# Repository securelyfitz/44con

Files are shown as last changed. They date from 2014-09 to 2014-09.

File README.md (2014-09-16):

44CON 2014 Badge
================

Based on the Dangerous Prototypes Bus Pirate V3c

Summary of changes:
-------------------
- changed PCB outline in dp_pcb.lbr
- added 44CON text in 44context.lbr
- added 1.8v LDO for using cpld without FTDI
- added LEDs and resistors on JP2 spare pins
- added 5x7mm Oscillator on pin 28
- added solder jumper near vtarget jumper

PCB Files
---------
* .sch and .brd: eagle schematic and board files 
* .lbr: eagle libraries for board outline and text items 
* .G* and .TXT: gerber files for fabricating board

CPLD Files
----------
* conled.v defines led flashing logic
* conled.v defines I/O pin assignments
* conled.jed xilinx bitstream file
* default.svf and default.xsvf bistream in generic format

Build options:
-------------
1. Generic USB Blaster for JTAG OCD, programming, and testing
1. Bare minimum CPLD build for flashing lights
1. Bare minimum CPLD build for cheap glitching

USB Blaster Build:
-----------------
see details on dangerous prototypes website:
http://dangerousprototypes.com/docs/Bus_Blaster_v3_design_overview

Flashy Light Build:
------------------

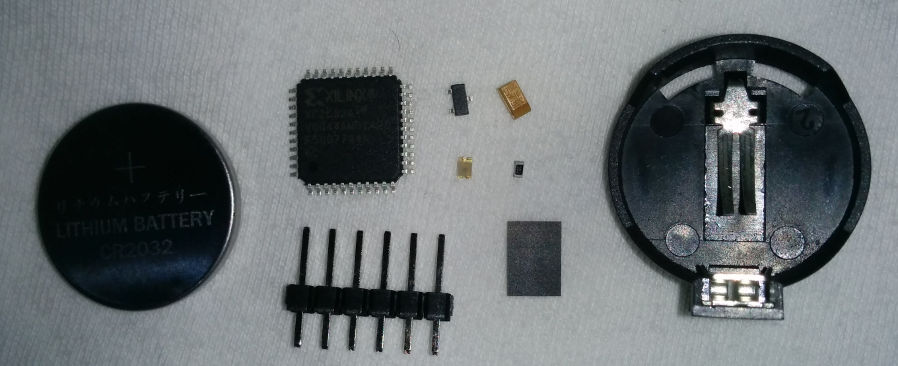
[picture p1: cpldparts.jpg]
cpld components


parts:
------
* CR2032 battery
* xilinx xc2c32a CPLD
* lm3480 1.8v regulator (note pinout!!!)
* 3.3nF tantalum capacitor
* 0805 LED x5
* 0603 50 ohm resistor
* .1" header for programming
* 5x7mm 50mhz (ish) oscillator
* CR2032 holder

building:
--------
1. solder battery holder onto the back of the board between jp2 3.3v pin and a JTAG GND pin
1. solder over the solder jumper in the upper right corner of the board
1. solder lm3480 just below and in between the FTDI and CPLD chips
  * if you have an AP7313 the pinout is different, rotate it clockwise 120 degrees and solder it
1. solder the tantalum capacitor on C2 with + towards the top of the PCB
1. put the CR2032 in and test that you have 3ish  volts on the 3.3v pins and 1.8 volts on the right lead of the regulator
1. remove the CR2032
1. solder the oscillator in the bottom right. Pin1 is in the far bottom right
1. solder the CPLD in place. Pin1 goes up
1. solder the resistors in place between the 2014 on the bottom. Resistors go on the upper pads
1. solder the LEDs below the resistors. + is to the left, - to the right
1. put the CR2032 back in and test for output from pin 3 of the oscillator (top left) with a multemeter to make sure it's not 0v
1. using a jtag programmer - Xilinx cable, Bus blaster, or a bus pirate in SVF mode - configure your CPLD and watch lights flash!

troubleshooting:
---------------
* if you can't recognize/configure the CPLD or lights are very dim, it could be a power issue. double check the 1.8v regulator and that the capacior is in the right direction.
* if the LEDs go on but don't flash, check your oscillator

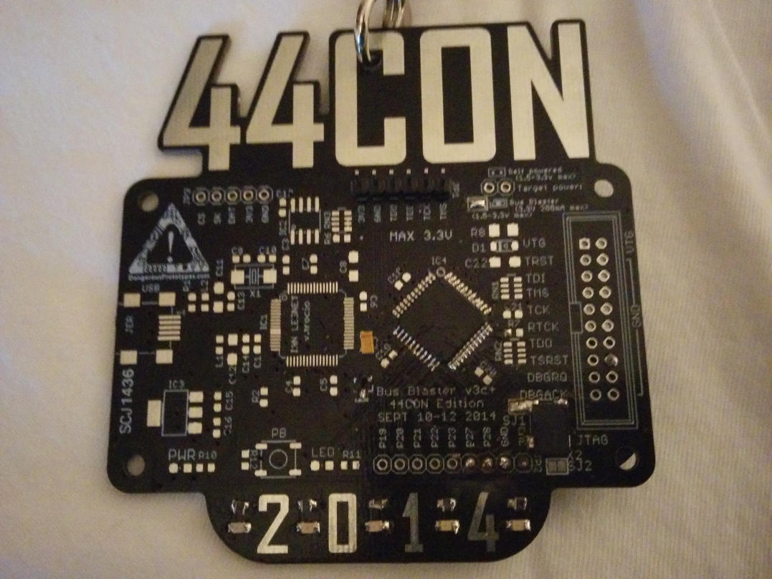
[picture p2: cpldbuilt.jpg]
cpld built


Glitching build:
----------------
same as flashy light build, though LEDS are optional. WIP to use it for glitching arduinos and/or XBOX360s

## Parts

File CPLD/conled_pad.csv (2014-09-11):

Release 8.1i - Fit P.20131013
Copyright(c) 1995-2003 Xilinx Inc. All rights reserved
9-10-2014 5:23PM
NOTE: This file is designed to be imported into a spreadsheet program
such as Microsoft Excel for viewing | printing and sorting. The comma ' | '
character is used as the data field separator.
This file is also designed to support parsing.
Input file: conled.ngd
output file: conled_pad.csv
Part type: xc2c32a
Speed grade: -6
Package: vq44
Pinout by Pin Number:
----- | ----- | ----- | ----- | ----- | ----- | ----- | ----- | ----- | -----
Pin Number | Signal Name | Pin Usage | Pin Name | Direction | IO Standard | IO Bank Number | {blank} | Slew Rate | Termination | {blank} | Voltage | Constraint
P1 | KPR |  | I/O/GCK2 |  |  | 1
P2 | KPR |  | I/O |  |  | 1
P3 | KPR |  | I/O |  |  | 1
P4 | GND |  | GND
P5 | KPR |  | I/O |  |  | 1
P6 | KPR |  | I/O |  |  | 1
P7 |  | VCCIO-UNUSED | VCCIO |  |  | 1
P8 | KPR |  | I/O |  |  | 1
P9 | TDI |  | TDI
P10 | TMS |  | TMS
P11 | TCK |  | TCK
P12 | KPR |  | I/O |  |  | 1
P13 | KPR |  | I/O |  |  | 1
P14 | KPR |  | I/O |  |  | 1
P15 |  | VCC | VCC
P16 | KPR |  | I/O |  |  | 1
P17 | GND |  | GND
P18 | KPR |  | I |  |  | 2
P19 | led0 | O | I/O | OUTPUT | LVCMOS18 | 2 |  | FAST
P20 | led1 | O | I/O | OUTPUT | LVCMOS18 | 2 |  | FAST
P21 | led2 | O | I/O | OUTPUT | LVCMOS18 | 2 |  | FAST
P22 | led3 | O | I/O | OUTPUT | LVCMOS18 | 2 |  | FAST
P23 | led4 | O | I/O | OUTPUT | LVCMOS18 | 2 |  | FAST
P24 | TDO |  | TDO
P25 | GND |  | GND
P26 |  | VCCIO-1.8 | VCCIO |  |  | 2
P27 | led5 | O | I/O | OUTPUT | LVCMOS18 | 2 |  | FAST
P28 | KPR |  | I/O |  |  | 2
P29 | KPR |  | I/O |  |  | 2
P30 | KPR |  | I/O/GSR |  |  | 2
P31 | KPR |  | I/O/GTS2 |  |  | 2
P32 | KPR |  | I/O/GTS3 |  |  | 2
P33 | KPR |  | I/O/GTS0 |  |  | 2
P34 | KPR |  | I/O/GTS1 |  |  | 2
P35 |  | VCCAUX | VAUX
P36 | KPR |  | I/O |  |  | 2
P37 | KPR |  | I/O |  |  | 2
P38 | KPR |  | I/O |  |  | 2
P39 | KPR |  | I/O |  |  | 1
P40 | KPR |  | I/O |  |  | 1
P41 | KPR |  | I/O |  |  | 1
P42 | KPR |  | I/O |  |  | 1
P43 | KPR |  | I/O/GCK0 |  |  | 1
P44 | KPR |  | I/O/GCK1 |  |  | 1
To preserve the pinout above for future design iterations in
Project Navigator simply execute the (Lock Pins) process
located under the (Implement Design) process in a toolbox named
(Optional Implementation Tools) or invoke PIN2UCF from the
command line. The location constraints will be written into your
specified UCF file

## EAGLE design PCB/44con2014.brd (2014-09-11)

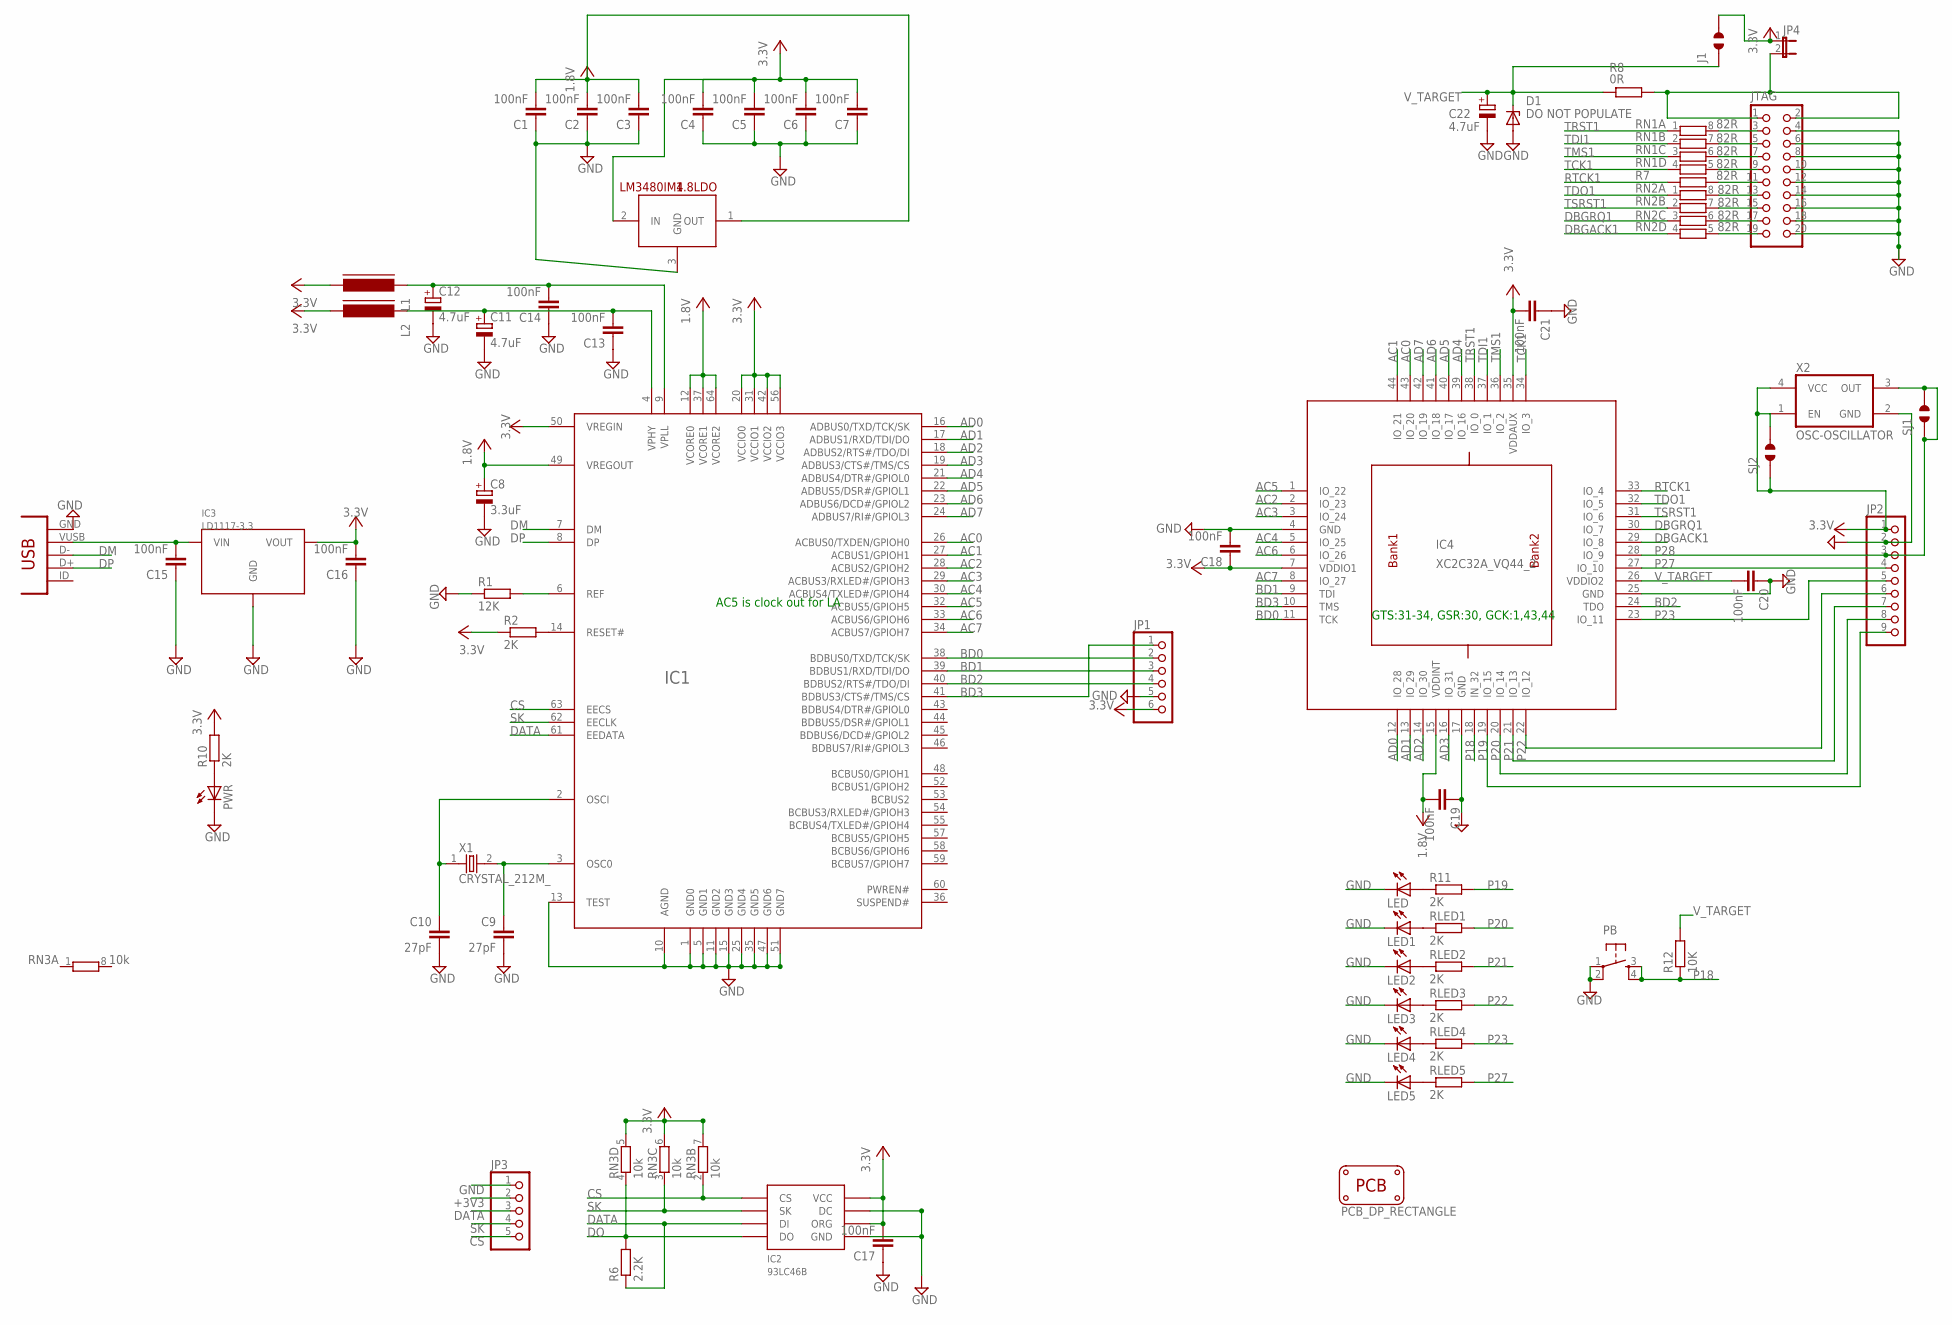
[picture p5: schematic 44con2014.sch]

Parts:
1.8LDO: LM3480IM4; SOT23-3
C1, C2, C3, C4, C5, C6, C7, C13, C14, C15, C16, C17, C18, C19, C20, C21: 100nF; C603
C8: 3.3uF; SMC_A
C9, C10: 27pF; C603
C11, C12, C22: 4.7uF; SMC_A
D1: DO NOT POPULATE; SOD-123
IC1: FT2232H; LQFP64
IC2: 93LC46B; SOIC8
IC3: LD1117-3.3; SOT223
IC4: XC2C32A_VQ44_2; VQ44
J1: JUMPER_SOLDER_1X2
JP1: PINHD-1X6; 1X06
JP2: PINHD-1X9; 1X09
JP3: PINHD-1X5; 1X05
JP4: JP1EJP; 1X02
JTAG: CON_HEADER_2X10-SHROUDED; PINSHRD_PTH_2X10
L1, L2: FERRITE_BEAD603; FB603
LED, LED1, LED2, LED3, LED4, LED5: LED805; LED-805
PB: SW-SMD-SMALL; TACT_SWITCH_SMALL
PCB3: PCB_DP_RECTANGLE; 44CON2014
PWR: LEDCHIPLED_0805; CHIPLED_0805
R1: 12K; R603
R2, R10, R11: 2K; R603
R6: 2.2K; R603
R7: 82R; R603
R8: 0R; R1206
R12: 10K; R603
RLED1, RLED2, RLED3, RLED4, RLED5: 2K; R603
RN1, RN2: 82R; RN8P-4R-CRA06S
RN3: 10k; RN8P-4R-CRA06S
SJ1, SJ2: JUMPER_SOLDER_1X2
USB: CON-USB-MINI-BUSB1; CONN_USB_MINI-B
X1: CRYSTAL_212M_; XTAL_4X6
X2: OSC-OSCILLATOR; OSCILLATOR_7X5_SMD

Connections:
1.8V: 1.8LDO.1 (OUT), C1.2, C2.2, C3.2, C8.+, C19.2, IC1.12 (VCORE0), IC1.37 (VCORE1), IC1.49 (VREGOUT), IC1.64 (VCORE2), IC4.15 (VDDINT)
+3V3: 1.8LDO.2 (IN), C4.2, C5.2, C6.2, C7.2, C16.2, C17.2, C18.1, C21.2, IC1.20 (VCCIO0), IC1.31 (VCCIO1), IC1.42 (VCCIO2), IC1.50 (VREGIN), IC1.56 (VCCIO3), IC2.6 (ORG), IC2.8 (VCC), IC3.2 (VOUT), IC4.7 (VDDIO1), IC4.35 (VDDAUX), J1.2, JP1.6, JP2.1, JP3.2, JP4.1, L1.2, L2.2, R2.1, R10.2, RN3.5 (2), RN3.6 (2), RN3.7 (2), SJ2.1, SJ2.2, X2.1 (EN), X2.4 (VCC)
AC0: IC1.26 (ACBUS0/TXDEN/GPIOH0), IC4.43 (IO_20)
AC1: IC1.27 (ACBUS1/GPIOH1), IC4.44 (IO_21)
AC2: IC1.28 (ACBUS2/GPIOH2), IC4.2 (IO_23)
AC3: IC1.29 (ACBUS3/RXLED#/GPIOH3), IC4.3 (IO_24)
AC4: IC1.30 (ACBUS4/TXLED#/GPIOH4), IC4.5 (IO_25)
AC5: IC1.32 (ACBUS5/GPIOH5), IC4.1 (IO_22)
AC6: IC1.33 (ACBUS6/GPIOH6), IC4.6 (IO_26)
AC7: IC1.34 (ACBUS7/GPIOH7), IC4.8 (IO_27)
AD0: IC1.16 (ADBUS0/TXD/TCK/SK), IC4.12 (IO_28)
AD1: IC1.17 (ADBUS1/RXD/TDI/DO), IC4.13 (IO_29)
AD2: IC1.18 (ADBUS2/RTS#/TDO/DI), IC4.14 (IO_30)
AD3: IC1.19 (ADBUS3/CTS#/TMS/CS), IC4.16 (IO_31)
AD4: IC1.21 (ADBUS4/DTR#/GPIOL0), IC4.39 (IO_16)
AD5: IC1.22 (ADBUS5/DSR#/GPIOL1), IC4.40 (IO_17)
AD6: IC1.23 (ADBUS6/DCD#/GPIOL2), IC4.41 (IO_18)
AD7: IC1.24 (ADBUS7/RI#/GPIOL3), IC4.42 (IO_19)
BD0: IC1.38 (BDBUS0/TXD/TCK/SK), IC4.11 (TCK), JP1.2
BD1: IC1.39 (BDBUS1/RXD/TDI/DO), IC4.9 (TDI), JP1.3
BD2: IC1.40 (BDBUS2/RTS#/TDO/DI), IC4.24 (TDO), JP1.4
BD3: IC1.41 (BDBUS3/CTS#/TMS/CS), IC4.10 (TMS), JP1.1
CS: IC1.63 (EECS), IC2.1 (CS), JP3.5, RN3.2 (1)
DATA: IC1.61 (EEDATA), IC2.3 (DI), JP3.3, R6.1
DBGACK1: IC4.29 (IO_8), RN2.4 (1)
DBGRQ1: IC4.30 (IO_7), RN2.3 (1)
DM: IC1.7 (DM), USB.D-
DO: IC2.4 (DO), R6.2, RN3.4 (1)
DP: IC1.8 (DP), USB.D+
GND: 1.8LDO.3 (GND), C1.1, C2.1, C3.1, C4.1, C5.1, C6.1, C7.1, C8.-, C9.2, C10.2, C11.-, C12.-, C13.1, C14.1, C15.1, C16.1, C17.1, C18.2, C19.1, C20.1, C21.1, C22.-, D1.A, IC1.1 (GND0), IC1.5 (GND1), IC1.10 (AGND), IC1.11 (GND2), IC1.13 (TEST), IC1.15 (GND3), IC1.25 (GND4), IC1.35 (GND5), IC1.47 (GND6), IC1.51 (GND7), IC2.5 (GND), IC2.7 (DC), IC3.1 (GND), IC4.4 (GND), IC4.17 (GND), IC4.25 (GND), JP1.5, JP2.2, JP3.1, JTAG.4, JTAG.6, JTAG.8, JTAG.10, JTAG.12, JTAG.14, JTAG.16, JTAG.18, JTAG.20, LED.C, LED1.C, LED2.C, LED3.C, LED4.C, LED5.C, PB.1, PB.2, PWR.C, R1.1, USB.GND, X2.2 (GND)
unnamed: C9.1, IC1.3 (OSC0), X1.2
unnamed: C10.1, IC1.2 (OSCI), X1.1
unnamed: IC1.14 (RESET#), R2.2
unnamed: IC1.6 (REF), R1.2
unnamed: C15.2, IC3.3 (VIN), USB.VUSB
unnamed: PWR.A, R10.1
unnamed: JTAG.3, RN1.8 (2)
unnamed: LED.A, R11.1
unnamed: JTAG.5, RN1.7 (2)
unnamed: JTAG.7, RN1.6 (2)
unnamed: JTAG.9, RN1.5 (2)
unnamed: JTAG.11, R7.2
unnamed: JTAG.13, RN2.8 (2)
unnamed: JTAG.15, RN2.7 (2)
unnamed: JTAG.17, RN2.6 (2)
unnamed: JTAG.19, RN2.5 (2)
unnamed: LED1.A, RLED1.1
unnamed: LED2.A, RLED2.1
unnamed: LED3.A, RLED3.1
unnamed: LED4.A, RLED4.1
unnamed: LED5.A, RLED5.1
P18: IC4.18 (IN_32), PB.3, PB.4, R12.1
P19: IC4.19 (IO_15), JP2.9, R11.2
P20: IC4.20 (IO_14), JP2.8, RLED1.2
P21: IC4.21 (IO_13), JP2.7, RLED2.2
P22: IC4.22 (IO_12), JP2.6, RLED3.2
P23: IC4.23 (IO_11), JP2.5, RLED4.2
P27: IC4.27 (IO_10), JP2.4, RLED5.2
P28: IC4.28 (IO_9), JP2.3, SJ1.1, SJ1.2, X2.3 (OUT)
RTCK1: IC4.33 (IO_4), R7.1
SK: IC1.62 (EECLK), IC2.2 (SK), JP3.4, RN3.3 (1)
TCK1: IC4.34 (IO_3), RN1.4 (1)
TDI1: IC4.37 (IO_1), RN1.2 (1)
TDO1: IC4.32 (IO_5), RN2.1
TMS1: IC4.36 (IO_2), RN1.3 (1)
TRST1: IC4.38 (IO_0), RN1.1
TSRST1: IC4.31 (IO_6), RN2.2 (1)
VPHY: C11.+, C13.2, IC1.4 (VPHY), L2.1
VPLL: C12.+, C14.2, IC1.9 (VPLL), L1.1
V_TARGET: C20.2, C22.+, D1.C, IC4.26 (VDDIO2), J1.1, R8.1, R12.2
V_TARGET_UNREG: JP4.2, JTAG.1, JTAG.2, R8.2

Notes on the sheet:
GTS:31-34, GSR:30, GCK:1,43,44
AC5 is clock out for LA

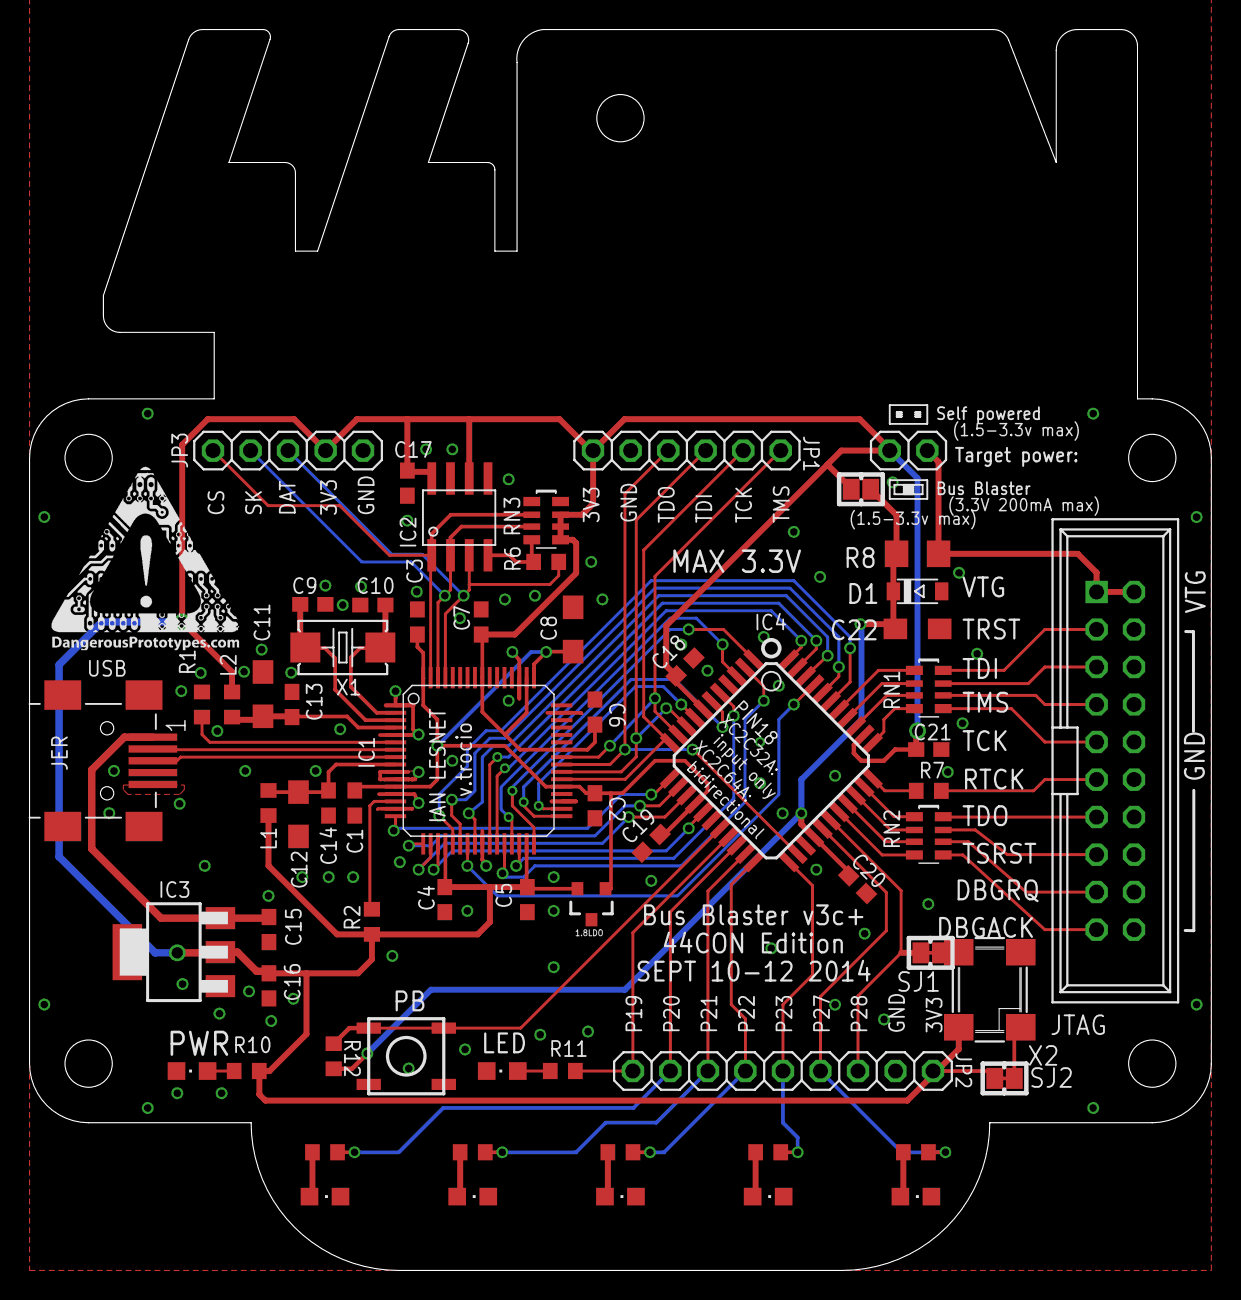
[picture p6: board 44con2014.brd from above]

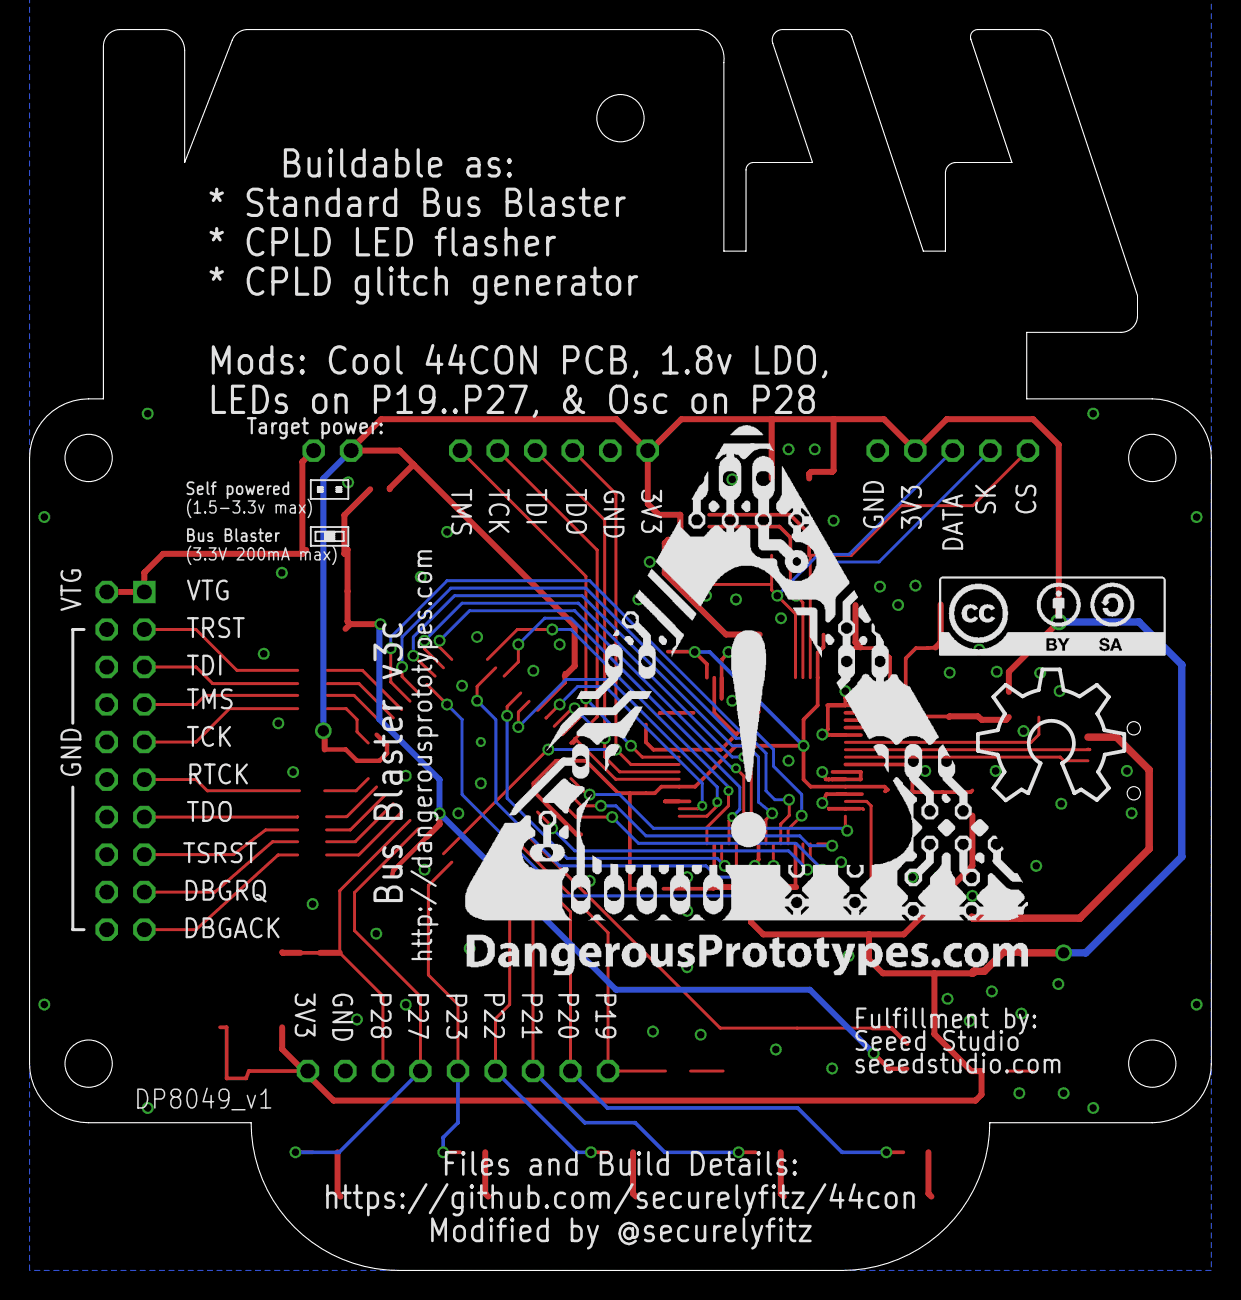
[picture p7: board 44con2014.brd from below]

Board: 2 copper layers, 80.0 x 84.0 mm, 76 parts (5 on the bottom side), 71 nets.

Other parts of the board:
U$1: DP_LOGO_ART_1.5X1.5
U$2: DP_LOGO_ART_0.5X0.5
U$3: CC-BY-SA
U$4: 44CON
U$5: OSHW_10X350_NOTEXT
U$6, U$9: adasdsd; JUMP2_DESC_ON
U$7, U$8: JUMP2_DESC_OFF
U$10: 2014

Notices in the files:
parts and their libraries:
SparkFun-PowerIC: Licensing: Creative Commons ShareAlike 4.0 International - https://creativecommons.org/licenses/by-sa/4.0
